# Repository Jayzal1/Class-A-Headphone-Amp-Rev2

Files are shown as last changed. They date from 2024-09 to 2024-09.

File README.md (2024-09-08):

# Class-A-Headphone-Amp-Rev2
Class A Headphone Amp Rev2

This is a design for a class A headphone amplifier with a case for mounting under a desk. It's pure analogue with phono rca input and a passthrough output which trigger when the amplifier is switch off. There is a built in linear pwoer supply running from a standard IEC Socket on the back panel. There are two front panel switches, left one is for power and the right one was intended to disable a 12v trigger option that was never implemented. The case is capable of being fully 3D printed. The case was built around an old headsink I had spare so if anyone would like to build this a redesign might be required to fit others. All the M3 panel screws are designed to run into [brass inserts]([url](https://www.google.com/search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)) which get melted into the 3D printed case.

Single Channel Schematic
Power Supply Schematic
PCB Layout
1725789058612(2)
1725788770056(2)
Case Render
Board 3D Render

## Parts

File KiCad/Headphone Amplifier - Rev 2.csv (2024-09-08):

# | Reference | Qty | Value | Footprint | DNP
1 | C1, C2, C17, C18 | 4 | 33uF | Capacitor_THT:C_Radial_D6.3mm_H11.0mm_P2.50mm
2 | C3, C8, C19, C20 | 4 | 470uF | Capacitor_THT:C_Radial_D10.0mm_H12.5mm_P5.00mm
3 | C4, C5 | 2 | 4700uF | Kerrin:Nichicon 4700uF, 35v, 85c - D18.0mm_H35.5mm_P7.50mm
4 | C6, C9 | 2 | 0.1uF | Capacitor_SMD:C_0603_1608Metric_Pad1.08x0.95mm_HandSolder
5 | C7, C11 | 2 | 1uF | Capacitor_SMD:C_0805_2012Metric_Pad1.18x1.45mm_HandSolder
6 | C10, C13 | 2 | 22uF | Capacitor_SMD:C_0805_2012Metric_Pad1.18x1.45mm_HandSolder
7 | D1, D2, D12, D13 | 4 | 1N4001 | Diode_THT:D_DO-41_SOD81_P10.16mm_Horizontal
8 | D3 | 1 | L Rectifier | Diode_THT:Diode_Bridge_Vishay_KBPC1
9 | D4 | 1 | R Rectifier | Diode_THT:Diode_Bridge_Vishay_KBPC1
10 | D5, D6, D7, D8 | 4 | 1N4002 | Diode_THT:D_DO-41_SOD81_P10.16mm_Horizontal
11 | D9 | 1 | PWR_LED | Kerrin:FrontPanel_LED_D3.0mm_Horizontal_O1.27mm_Z6.0mm
12 | F1, F2, F3 | 3 | Fuse | Kerrin:Amazon_Fuseholder-5x20mm_Littelfuse_111_Inline_P20.00x5.00mm_D1.05mm
13 | J1 | 1 | Signal In | Connector_Wire:SolderWire-0.5sqmm_1x03_P4.6mm_D0.9mm_OD2.1mm
14 | J2 | 1 | Signal Output | Kerrin:NMJ6HC-S
15 | J3 | 1 | Mains Input | Connector_Wire:SolderWire-0.75sqmm_1x02_P7mm_D1.25mm_OD3.5mm
16 | Q1, Q3 | 2 | 2SC1815 | Package_TO_SOT_THT:TO-92_Inline_Wide
17 | R1, R2, R12, R13 | 4 | 10K | Kerrin:Resistor_Axial_0.25W_L6.3mm_D2.5mm_P10.16mm
18 | R3, R14 | 2 | 15K | Kerrin:Resistor_Axial_0.25W_L6.3mm_D2.5mm_P10.16mm
19 | R4, R7 | 2 | R240 | Kerrin:Resistor_Axial_0.25W_L6.3mm_D2.5mm_P10.16mm
20 | R5, R6 | 2 | 5K | Kerrin:Potentiometer_Bourns_3296W_Vertical
21 | R8 | 1 | 2K | Kerrin:Resistor_Axial_0.25W_L6.3mm_D2.5mm_P10.16mm
22 | R9, R10 | 2 | 1K | Kerrin:Resistor_Axial_0.25W_L6.3mm_D2.5mm_P10.16mm
23 | R11, R15 | 2 | 1R | Kerrin:Resistor_Axial_0.25W_L6.3mm_D2.5mm_P10.16mm
24 | RV3, RV4, RV11, RV12 | 4 | 10K | Kerrin:Potentiometer_Bourns_3296W_Vertical
25 | RV7 | 1 | Dual 100K Vol Pot | Kerrin:Dual_Potentiometer_Horizontal
26 | T1 | 1 | Myrra_41176_15v_10VA_Transformer | Kerrin:Myrra_44274_15v_10VA_Transformer
27 | U1, U2, U7, U8 | 4 | TIP31C | Kerrin:TO-220-3_Horizontal_TabUp_FlatLegs
28 | U3, U4 | 2 | LM317 | Kerrin:TO-220-3_Horizontal_TabUp_FlatLegs

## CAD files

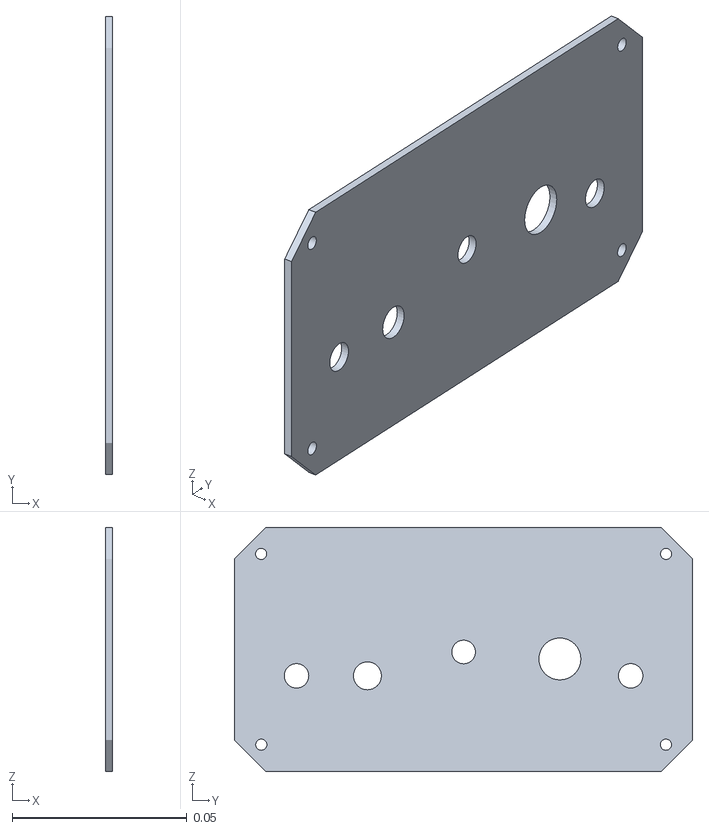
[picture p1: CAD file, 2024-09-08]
Chassis/Front Panel v1.stl
0.002 x 0.131 x 0.0698

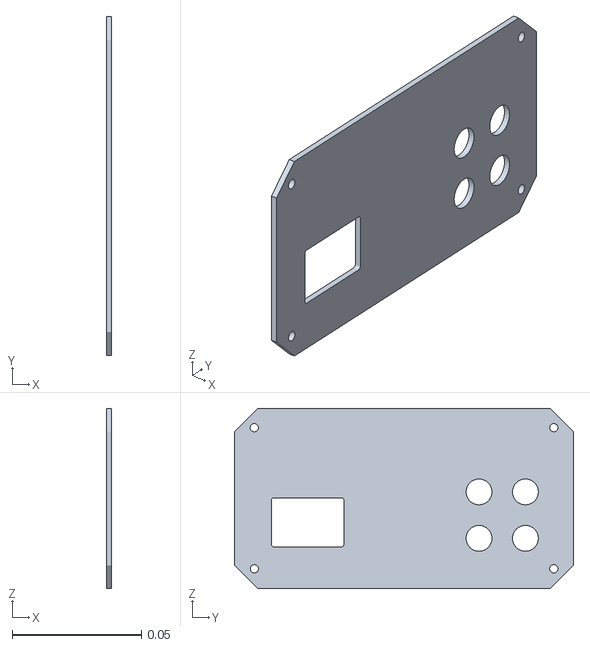
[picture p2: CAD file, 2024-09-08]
Chassis/Back Panel v1.stl
0.002 x 0.131 x 0.0697

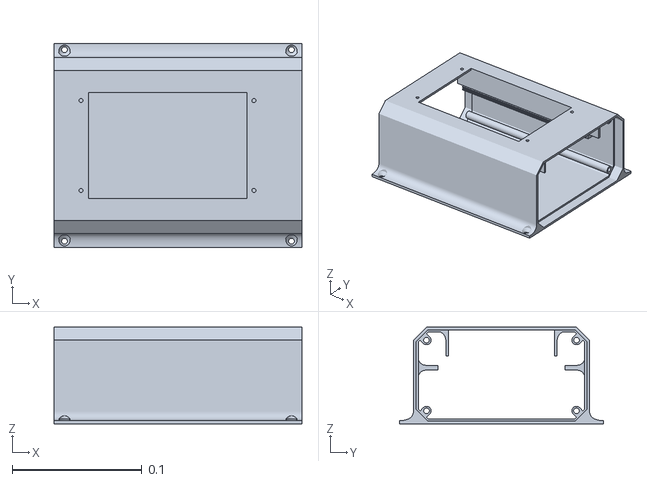
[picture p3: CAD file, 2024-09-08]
Chassis/Class A Rev 2 - Case.stl
0.191 x 0.157 x 0.0746

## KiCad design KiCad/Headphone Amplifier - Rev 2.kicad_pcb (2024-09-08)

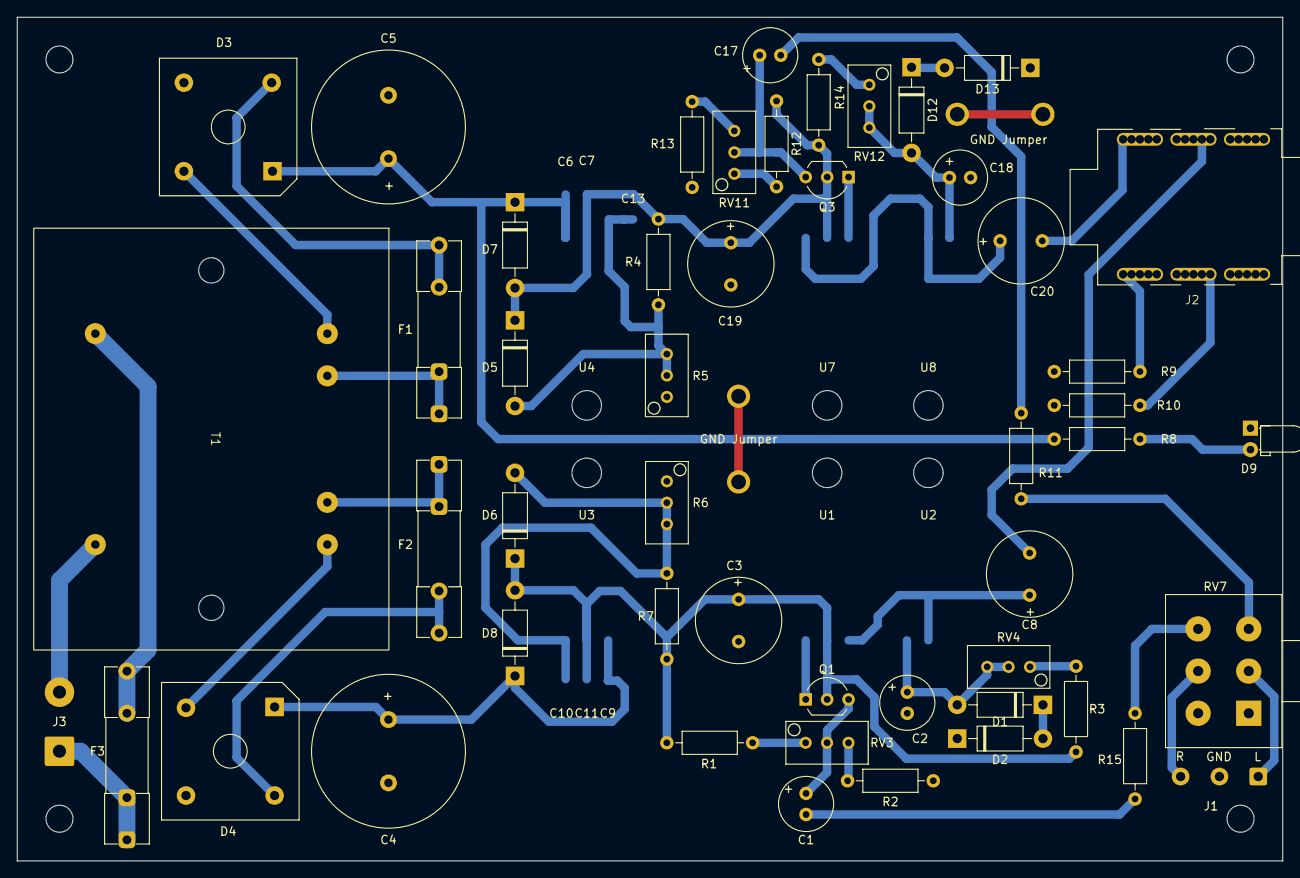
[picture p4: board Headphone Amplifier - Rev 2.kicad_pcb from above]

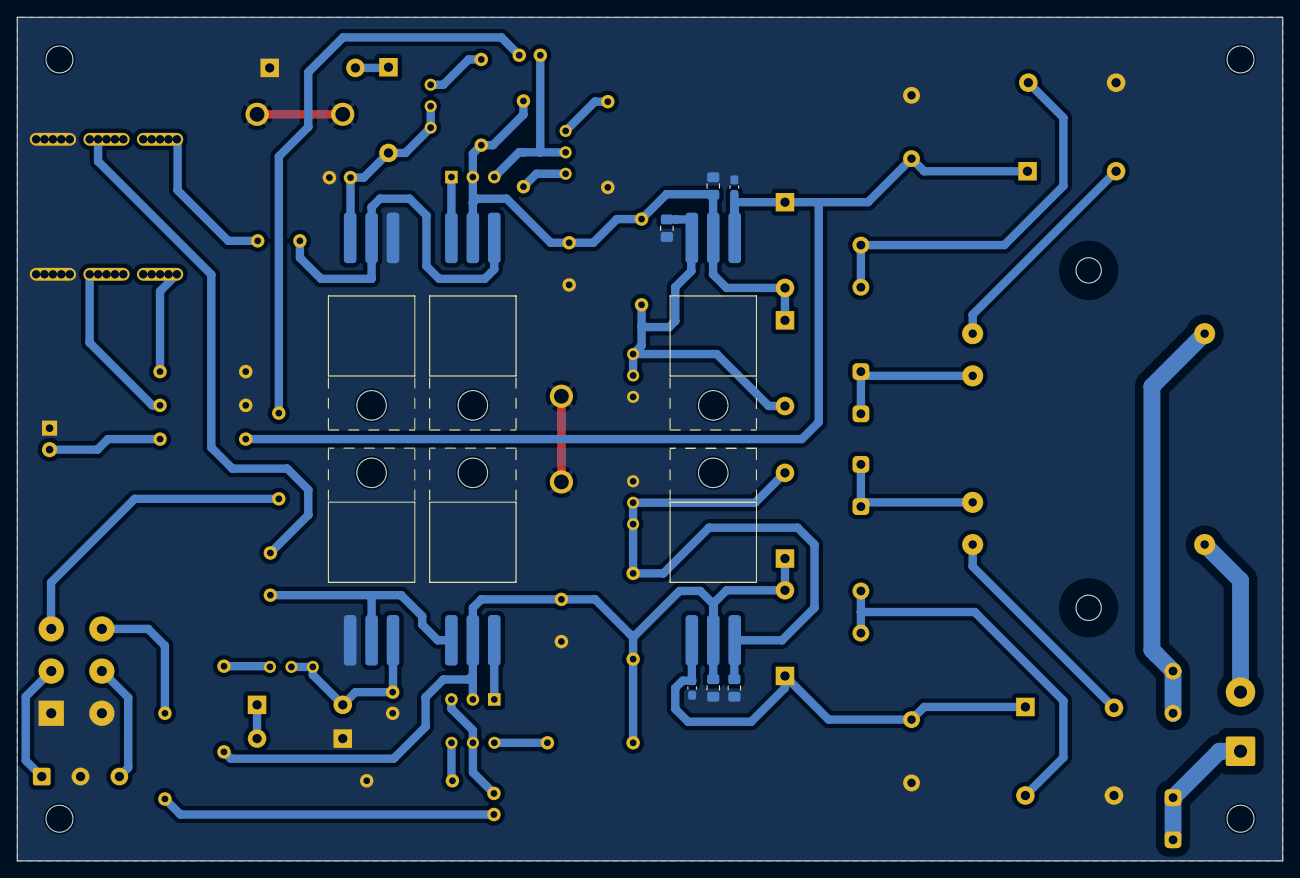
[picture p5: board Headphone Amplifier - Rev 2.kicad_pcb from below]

Board: 2 copper layers, 150.0 x 100.0 mm, 64 parts (12 on the bottom side), 43 nets.

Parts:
C1, C2, C17, C18: 33uF; C_Radial_D6.3mm_H11.0mm_P2.50mm
C3, C8, C19, C20: 470uF; C_Radial_D10.0mm_H12.5mm_P5.00mm
C4, C5: 4700uF; Nichicon 4700uF, 35v, 85c - D18.0mm_H35.5mm_P7.50mm
C6, C9: 0.1uF; C_0603_1608Metric_Pad1.08x0.95mm_HandSolder
C7, C11: 1uF; C_0805_2012Metric_Pad1.18x1.45mm_HandSolder
C10, C13: 22uF; C_0805_2012Metric_Pad1.18x1.45mm_HandSolder
D1, D2, D12, D13: 1N4001; D_DO-41_SOD81_P10.16mm_Horizontal
D3: L Rectifier; Diode_Bridge_Vishay_KBPC1
D4: R Rectifier; Diode_Bridge_Vishay_KBPC1
D5, D6, D7, D8: 1N4002; D_DO-41_SOD81_P10.16mm_Horizontal
D9: PWR_LED; FrontPanel_LED_D3.0mm_Horizontal_O1.27mm_Z6.0mm
F1, F2, F3: Fuse; Amazon_Fuseholder-5x20mm_Littelfuse_111_Inline_P20.00x5.00m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
GND Jumper: SolderWire-1sqmm_1x02_P5.4mm_D1.4mm_OD2.7mm
GND Jumper#2: SolderWire-1sqmm_1x02_P5.4mm_D1.4mm_OD2.7mm
J1: Signal In; SolderWire-0.5sqmm_1x03_P4.6mm_D0.9mm_OD2.1mm
J2: Signal Output; NMJ6HC-S
J3: Mains Input; SolderWire-0.75sqmm_1x02_P7mm_D1.25mm_OD3.5mm
Q1, Q3: 2SC1815; TO-92_Inline_Wide
R1, R2, R12, R13: 10K; Resistor_Axial_0.25W_L6.3mm_D2.5mm_P10.16mm
R3, R14: 15K; Resistor_Axial_0.25W_L6.3mm_D2.5mm_P10.16mm
R4, R7: R220; Resistor_Axial_0.25W_L6.3mm_D2.5mm_P10.16mm
R5, R6: 5K; Potentiometer_Bourns_3296W_Vertical
R8: 2K; Resistor_Axial_0.25W_L6.3mm_D2.5mm_P10.16mm
R9, R10: 1K; Resistor_Axial_0.25W_L6.3mm_D2.5mm_P10.16mm
R11, R15: 1R; Resistor_Axial_0.25W_L6.3mm_D2.5mm_P10.16mm
RV3, RV4, RV11, RV12: 10K; Potentiometer_Bourns_3296W_Vertical
RV7: Dual 100K Vol Pot; Dual_Potentiometer_Horizontal
T1: Myrra_41176_15v_10VA_Transformer; Myrra_44274_15v_10VA_Transformer
U1, U2, U7, U8: TIP31C; TO-220-3_Horizontal_TabUp_FlatLegs
U3, U4: LM317; TO-220-3_Horizontal_TabUp_FlatLegs

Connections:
/Left Amplifier Channel/15V: C7.1, C19.1, D5.1 (K), D7.2 (A), Q3.2 (C), R4.2, R12.1, R14.1, U4.2 (VO), U7.2
/Left Amplifier Channel/Signal Input: R11.1, RV7.3
/Left Amplifier Channel/Signal Output: C20.2, J2.T
/Power Supply/17.3v AC: D3.4, T1.12
/Power Supply/22.9v: C5.1, C6.1, D3.1 (+), D7.1 (K), R8.2, U4.3 (VI)
/Power Supply/+15V (R): C3.1, C11.1, D6.1 (K), D8.2 (A), Q1.2 (C), R1.1, R3.1, R7.2, U1.2, U3.2 (VO)
/Right Amplifier Channel/Signal Input: R15.1, RV7.6
/Right Amplifier Channel/Signal Output: C8.2, J2.R
GND: C2.2, C3.2, C4.2, C5.2, C6.2, C7.2, C9.2, C10.2, C11.2, C13.2, C18.2, C19.2, D2.1 (K), D3.3 (-), D4.3 (-), D9.1 (K), D13.1 (K), GND Jumper.1, GND Jumper.2, GND Jumper#2.1, GND Jumper#2.2, J1.2, J2.S, J2.SN, R2.2, R5.1, R6.1, R9.2, R10.2, R13.2, RV7.1, RV7.4, U2.3, U8.3
unnamed: C1.2, R15.2
unnamed: C8.1, U1.3, U2.2
unnamed: C17.2, R11.2
unnamed: C20.1, U7.3, U8.2
unnamed: C2.1, D1.2 (A), RV4.2, RV4.3, U2.1
unnamed: D1.1 (K), D2.2 (A)
unnamed: D3.2, F1.2
unnamed: C4.1, C9.1, D4.1 (+), D8.1 (K), U3.3 (VI)
unnamed: D4.2, T1.7
unnamed: D4.4, F2.2
unnamed: C13.1, D5.2 (A), R4.1, R5.2, R5.3, U4.1 (ADJ)
unnamed: C10.1, D6.2 (A), R6.2, R6.3, R7.1, U3.1 (ADJ)
unnamed: D9.2 (A), R8.1
unnamed: C18.1, D12.2 (A), RV12.2, RV12.3, U8.1
unnamed: D12.1 (K), D13.2 (A)
unnamed: F1.1, T1.11
unnamed: F2.1, T1.8
unnamed: F3.2, T1.1
unnamed: J1.1, RV7.2
unnamed: J1.3, RV7.5
unnamed: J2.RN, R10.1
unnamed: J2.TN, R9.1
unnamed: F3.1, J3.1
unnamed: J3.2, T1.6
unnamed: C1.1, Q1.3 (B), RV3.2
unnamed: Q1.1 (E), U1.1
unnamed: C17.1, Q3.3 (B), RV11.2
unnamed: Q3.1 (E), U7.1
unnamed: R1.2, RV3.1
unnamed: R2.1, RV3.3
unnamed: R3.2, RV4.1
unnamed: R12.2, RV11.1
unnamed: R13.1, RV11.3
unnamed: R14.2, RV12.1
